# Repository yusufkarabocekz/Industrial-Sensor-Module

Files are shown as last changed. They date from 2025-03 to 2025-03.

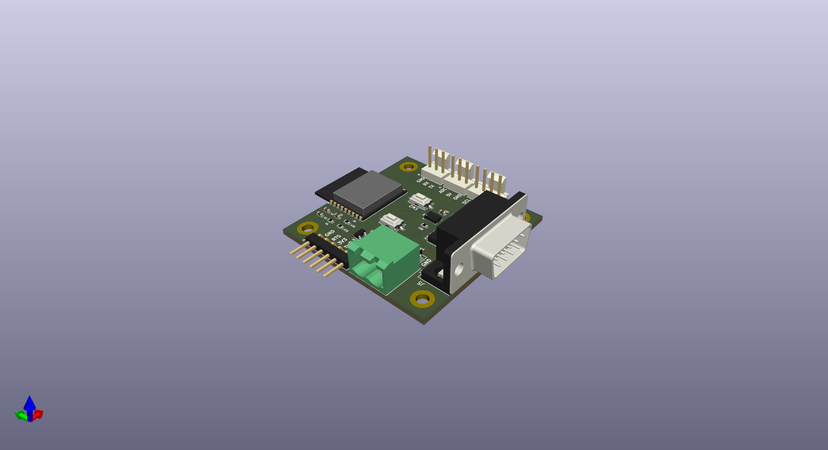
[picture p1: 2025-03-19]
Endüstriyel Sensör Modülü Front Cross.png

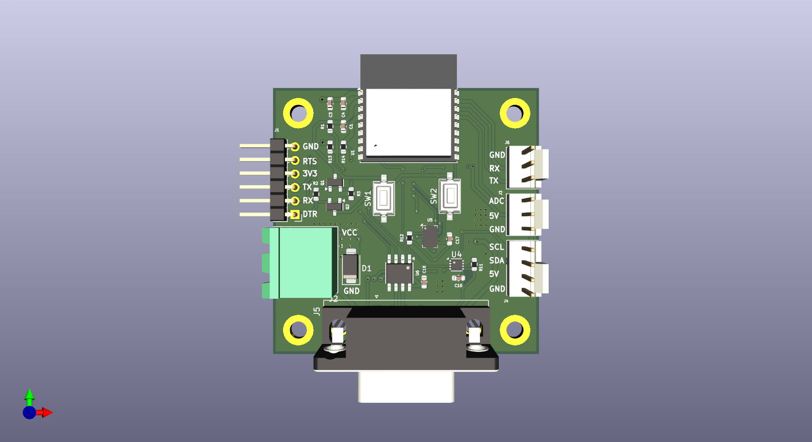
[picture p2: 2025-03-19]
Endüstriyel Sensör Modülü Front.png

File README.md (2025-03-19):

# Industrial Sensor Module

## Overview
This industrial sensor module is designed for factory automation applications, providing real-time environmental monitoring of temperature, humidity, and air quality (VOC). The module is built to withstand harsh industrial conditions and supports multiple communication protocols, making it a versatile solution for various automation systems.

## Features
- **Power Input:** 9-24V DC
- **Voltage Regulation:**
  - 5V and 3.3V regulators (LDO and DC-DC buck converter)
- **Sensors:**
  - SHT31 (Temperature & Humidity, I2C)
  - CCS811 (VOC and CO2, I2C)
  - External Analog Input (0-5V, read through 12-bit ADC)
- **Communication Interfaces:**
  - RS485 (Modbus RTU support)
  - UART & I2C external pins
  - ESP32C3 Mini onboard
- **PCB Specifications:**
  - **Dimensions:** 50mm x 50mm
  - **Layer Count:** 4-layer PCB for improved signal integrity and EMI resistance
  - **Terminal Blocks:** Phoenix Contact (or equivalent) screw terminals for RS485 and power input
  - **ESD Protection:** TVS diodes on input lines to ensure robustness

## PCB Design
The PCB layout is optimized to minimize the influence of airflow on sensor measurements. The module is compact, modular, and suitable for various industrial applications.

## PCB Images
### Front View
The front side of the PCB features the ESP32C3 Mini, sensor modules, and necessary components for power regulation and communication. 
Endüstriyel Sensör Modülü Front

### Back View
The back side of the PCB includes additional circuit traces, connectors, and protection components. 
Endüstriyel Sensör Modülü Front Bottom

### Angled View
This perspective provides a detailed look at the board's overall design, component placement, and the layout strategy used to optimize performance and durability.
Endüstriyel Sensör Modülü Front Cross

## Getting Started
### Hardware Setup
1. Provide a **9-24V DC** power input via the terminal block.
2. Connect RS485 for Modbus RTU communication or use UART/I2C for direct interfacing.
3. Read sensor values via ESP32C3 Mini or any other microcontroller with supported interfaces.

### Firmware Development
- The ESP32C3 Mini can be programmed using **ESP-IDF** or **Arduino framework**.
- Libraries required:
  - `Wire.h` for I2C communication
  - `ModbusMaster.h` for Modbus RTU communication (if needed)
  - `Adafruit_SHT31.h` for SHT31 sensor
  - `Adafruit_CCS811.h` for CCS811 sensor

## Gerber Files & Manufacturing
- The **Gerber files** are available in the `gerber/` directory.
- Recommended PCB manufacturing specs:
  - **Layer Count:** 4
  - **Copper Thickness:** 1oz
  - **Surface Finish:** ENIG

## Contact
For any inquiries or contributions, feel free to open an issue or reach out.

---
_Designed with KiCad._ Designed by Yusuf Karabocek

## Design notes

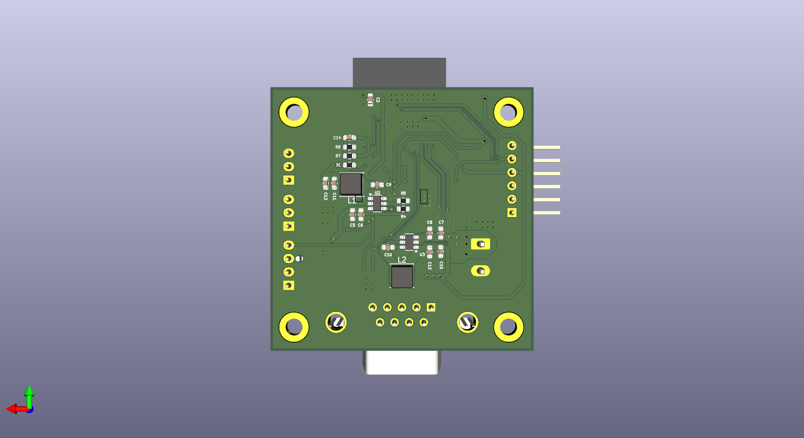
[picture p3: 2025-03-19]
Endüstriyel Sensör Modülü Front Bottom.png

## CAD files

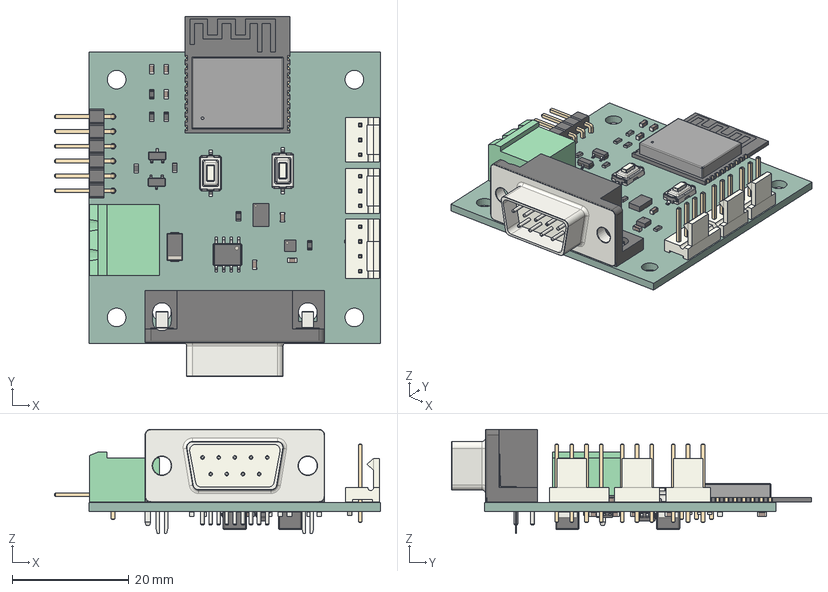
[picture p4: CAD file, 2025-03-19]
Endüstriyel Sensör Modülü.step
55.9 x 61.7 x 17.9 mm
C_0603_1608Metric x 18
D_SMA
SOIC-8_3.9x4.9mm_P1.27mm
SOT-23 x 2
SW_Tactile_SPST_NO_Straight_CK_PTS636Sx25SMTRLFS x 2
R_0603_1608Metric x 12
ESP32-C3-WROOM-02
PinHeader_1x06_P2.54mm_Horizontal
DSUB-9_Pins_Horizontal_P2.77x2.84mm_EdgePinOffset4.94mm_Housed_ MountingHolesOffset4.94mm
DFN-8-1EP_2x2mm_P0.5mm_EP0.6x1.2mm
PhoenixContact_MSTBA_2,5_2-G-5,08_1x02_P5.08mm_Horizontal
FanPinHeader_1x03_P2.54mm_Vertical x 2
FanPinHeader_1x04_P2.54mm_Vertical
AMS_LGA-10-1EP_2.7x4mm_P0.6mm
L_APV_ANR4030 x 2
TSOT-23-6
SOT-23-6
EndÃ¼striyel SensÃ¶r ModÃ¼lÃ¼_PCB

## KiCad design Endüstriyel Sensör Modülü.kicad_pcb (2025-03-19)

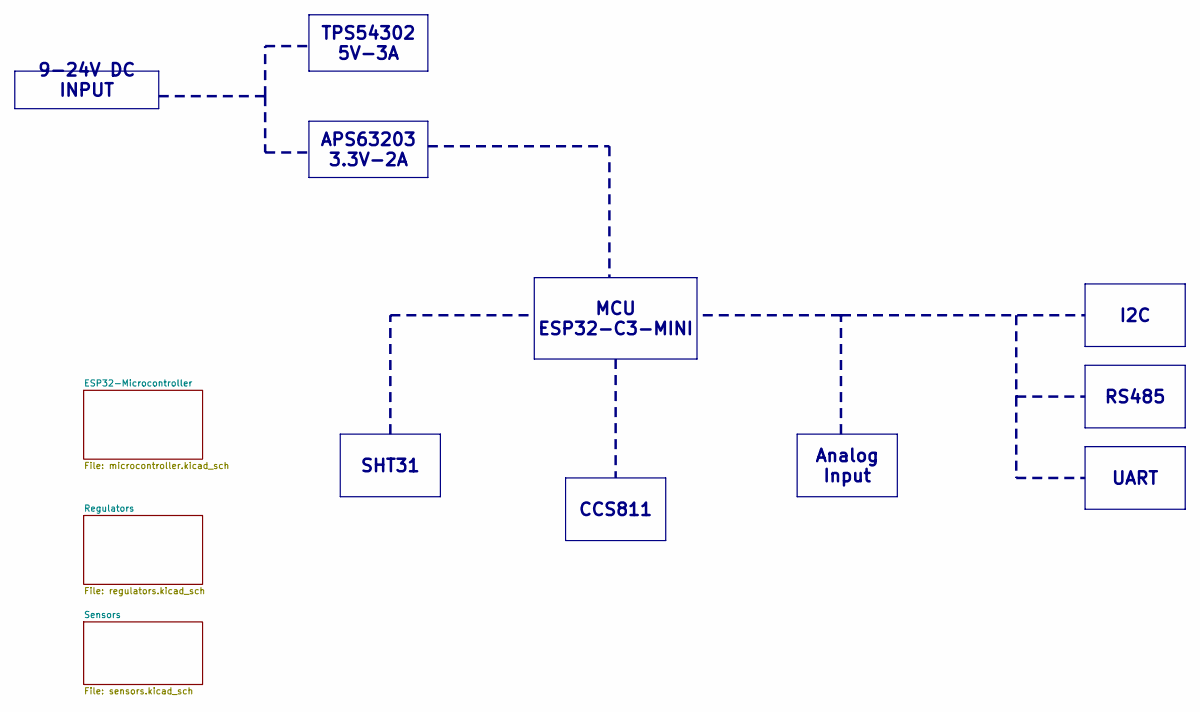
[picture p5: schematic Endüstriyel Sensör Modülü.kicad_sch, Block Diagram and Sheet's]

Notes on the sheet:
SHT31
MCU ESP32-C3-MINI
CCS811
APS63203 3.3V-2A
I2C
Analog Input
UART
9-24V DC INPUT
TPS54302 5V-3A
RS485

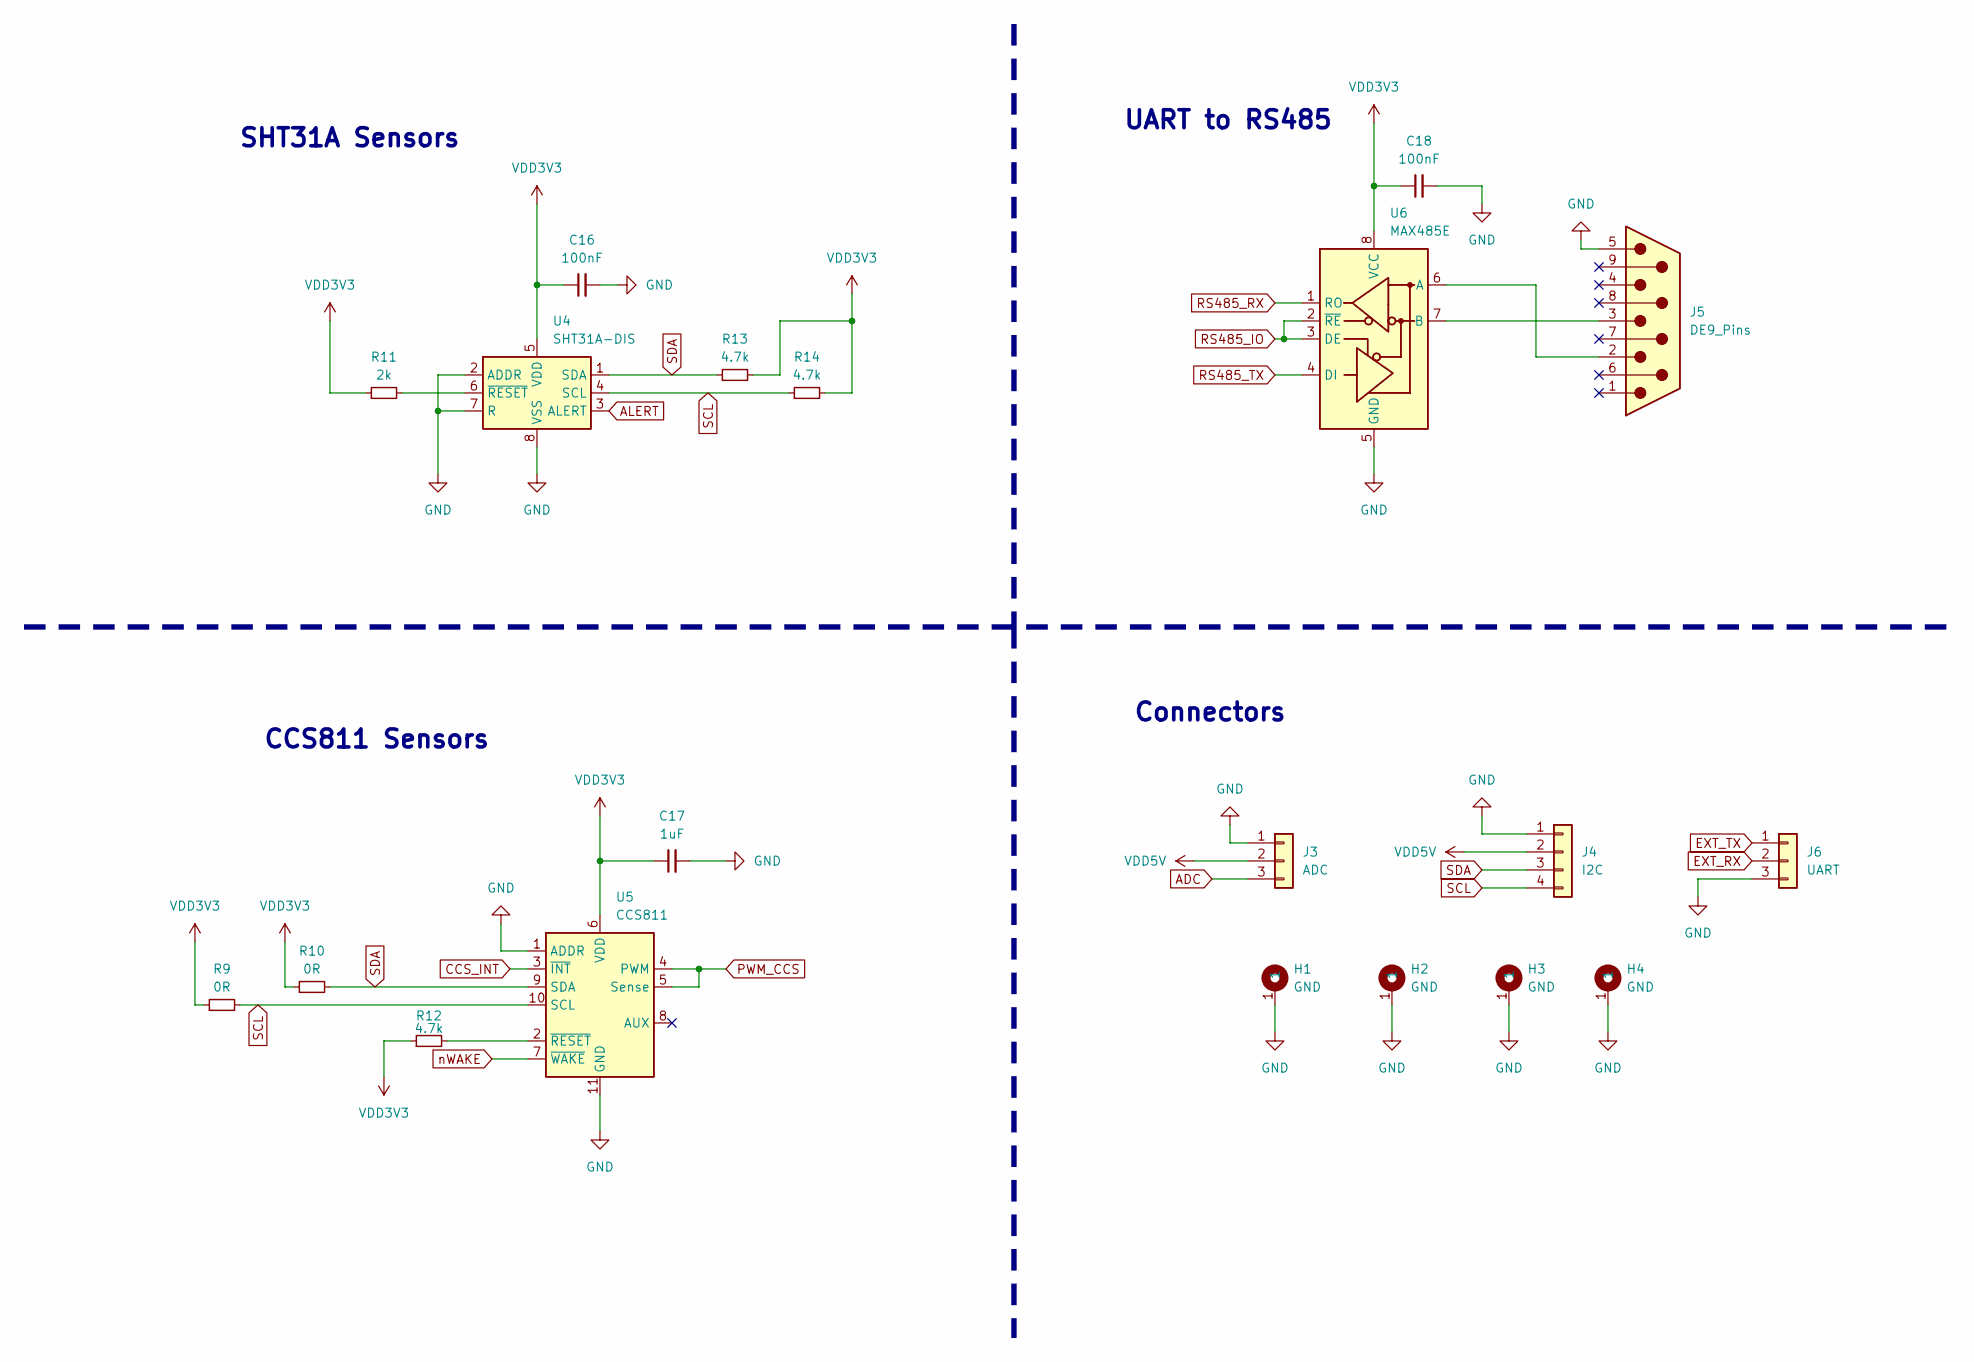
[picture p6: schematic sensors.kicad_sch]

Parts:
C16, C18: 100nF; C_0603_1608Metric
C17: 1uF; C_0603_1608Metric
H1, H2, H3, H4: GND; MountingHole_3.2mm_M3_ISO7380_Pad_TopBottom
J3: ADC; FanPinHeader_1x03_P2.54mm_Vertical
J4: I2C; FanPinHeader_1x04_P2.54mm_Vertical
J5: DE9_Pins; DSUB-9_Pins_Horizontal_P2.77x2.84mm_EdgePinOffset4.94mm_Hou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
J6: UART; FanPinHeader_1x03_P2.54mm_Vertical
R9, R10: 0R; R_0603_1608Metric
R11: 2k; R_0603_1608Metric
R12, R13, R14: 4.7k; R_0603_1608Metric
U4: SHT31A-DIS; DFN-8-1EP_2x2mm_P0.5mm_EP0.6x1.2mm
U5: CCS811; AMS_LGA-10-1EP_2.7x4mm_P0.6mm
U6: MAX485E; SOIC-8_3.9x4.9mm_P1.27mm

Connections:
ADC: J3.3; also elsewhere on the board
ALERT: U4.3 (ALERT); also elsewhere on the board
CCS_INT: U5.3 (~INT); also elsewhere on the board
EXT_RX: J6.2; also elsewhere on the board
EXT_TX: J6.1; also elsewhere on the board
GND: C16.2, C17.2, C18.2, H1.1, H2.1, H3.1, H4.1, J3.1, J4.1, J5.5, J6.3, U4.2 (ADDR), U4.7 (R), U4.8 (VSS), U4.9 (VSS), U5.1 (ADDR), U5.11 (GND), U6.5 (GND); also elsewhere on the board
unnamed: R11.2, U4.6 (~RESET)
unnamed: R12.2, U5.2 (~RESET)
unnamed: J5.2, U6.6 (A)
unnamed: J5.3, U6.7 (B)
PWM_CCS: U5.4 (PWM), U5.5 (Sense); also elsewhere on the board
RS485_IO: U6.2 (~RE), U6.3 (DE); also elsewhere on the board
RS485_RX: U6.1 (RO); also elsewhere on the board
RS485_TX: U6.4 (DI); also elsewhere on the board
SCL: J4.4, R9.2, R14.1, U4.4 (SCL), U5.10 (SCL); also elsewhere on the board
SDA: J4.3, R10.2, R13.1, U4.1 (SDA), U5.9 (SDA); also elsewhere on the board
VDD3V3: C16.1, C17.1, C18.1, R9.1, R10.1, R11.1, R12.1, R13.2, R14.2, U4.5 (VDD), U5.6 (VDD), U6.8 (VCC); also elsewhere on the board
VDD5V: J3.2, J4.2; also elsewhere on the board
nWAKE: U5.7 (~WAKE); also elsewhere on the board

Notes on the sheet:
UART to RS485
CCS811 Sensors
Connectors
SHT31A Sensors

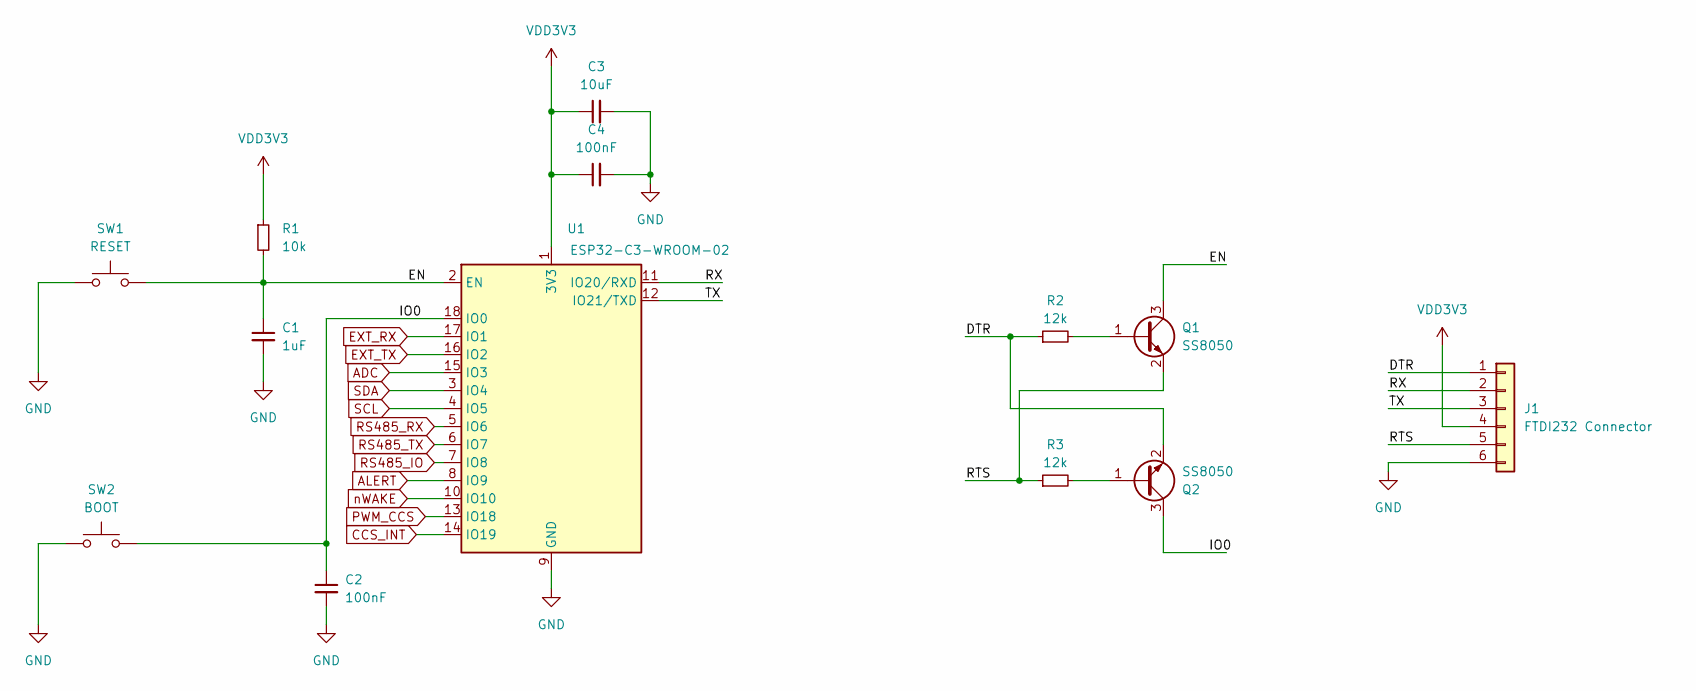
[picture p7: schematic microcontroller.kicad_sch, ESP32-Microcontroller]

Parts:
C1: 1uF; C_0603_1608Metric
C2, C4: 100nF; C_0603_1608Metric
C3: 10uF; C_0603_1608Metric
J1: FTDI232 Connector; PinHeader_1x06_P2.54mm_Horizontal
Q1, Q2: SS8050; SOT-23
R1: 10k; R_0603_1608Metric
R2, R3: 12k; R_0603_1608Metric
SW1: RESET; SW_Tactile_SPST_NO_Straight_CK_PTS636Sx25SMTRLFS
SW2: BOOT; SW_Tactile_SPST_NO_Straight_CK_PTS636Sx25SMTRLFS
U1: ESP32-C3-WROOM-02

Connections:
/ESP32-Microcontroller/DTR: J1.1, Q2.2 (E), R2.1
/ESP32-Microcontroller/EN: C1.1, Q1.3 (C), R1.2, SW1.2, U1.2 (EN)
/ESP32-Microcontroller/IO0: C2.1, Q2.3 (C), SW2.2, U1.18 (IO0)
/ESP32-Microcontroller/RTS: J1.5, Q1.2 (E), R3.1
/ESP32-Microcontroller/RX: J1.2, U1.11 (IO20/RXD)
/ESP32-Microcontroller/TX: J1.3, U1.12 (IO21/TXD)
ADC: U1.15 (IO3); also elsewhere on the board
ALERT: U1.8 (IO9); also elsewhere on the board
CCS_INT: U1.14 (IO19); also elsewhere on the board
EXT_RX: U1.17 (IO1); also elsewhere on the board
EXT_TX: U1.16 (IO2); also elsewhere on the board
GND: C1.2, C2.2, C3.2, C4.2, J1.6, SW1.1, SW2.1, U1.9 (GND), U1.19 (GND); also elsewhere on the board
unnamed: Q1.1 (B), R2.2
unnamed: Q2.1 (B), R3.2
PWM_CCS: U1.13 (IO18); also elsewhere on the board
RS485_IO: U1.7 (IO8); also elsewhere on the board
RS485_RX: U1.5 (IO6); also elsewhere on the board
RS485_TX: U1.6 (IO7); also elsewhere on the board
SCL: U1.4 (IO5); also elsewhere on the board
SDA: U1.3 (IO4); also elsewhere on the board
VDD3V3: C3.1, C4.1, J1.4, R1.1, U1.1 (3V3); also elsewhere on the board
nWAKE: U1.10 (IO10); also elsewhere on the board

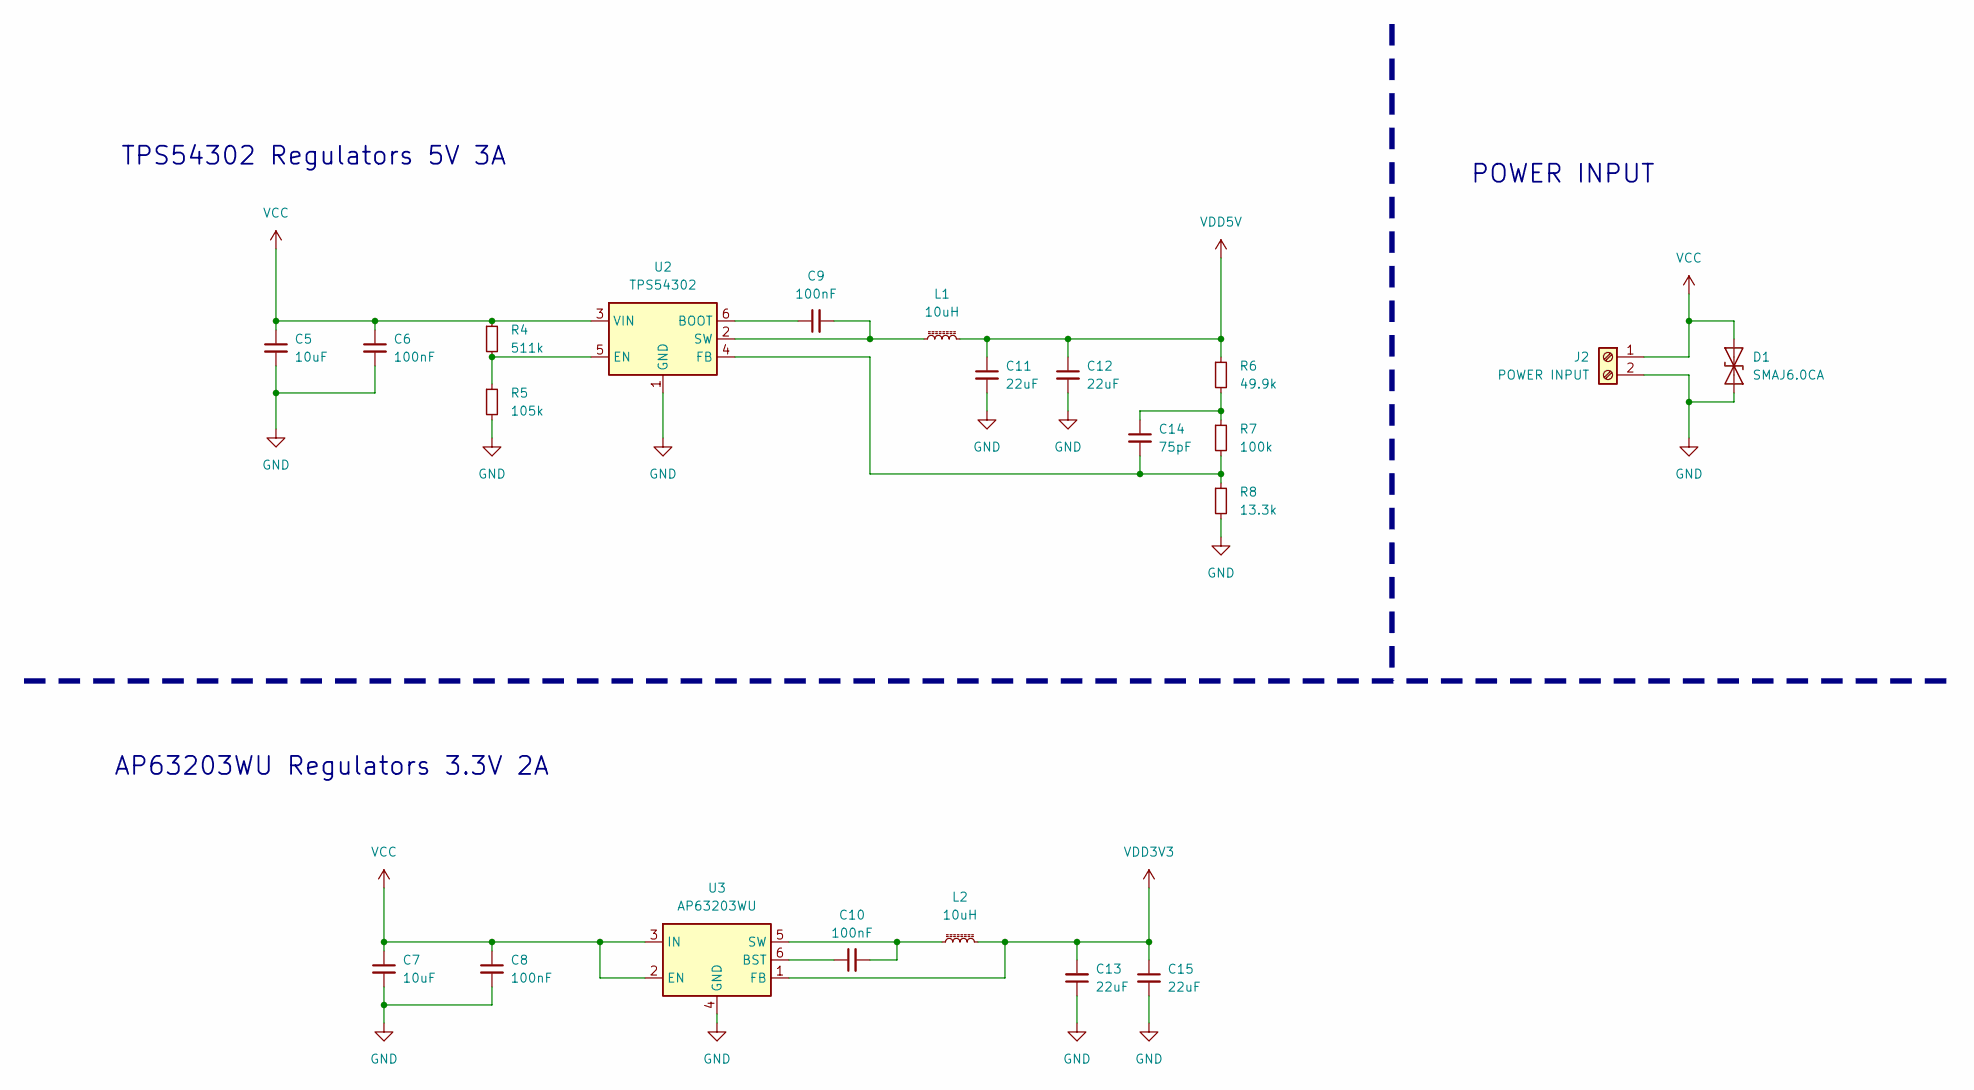
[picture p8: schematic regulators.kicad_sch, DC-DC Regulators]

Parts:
C5, C7: 10uF; C_0603_1608Metric
C6, C8, C9, C10: 100nF; C_0603_1608Metric
C11, C12, C13, C15: 22uF; C_0603_1608Metric
C14: 75pF; C_0603_1608Metric
D1: SMAJ6.0CA; D_SMA
J2: POWER INPUT; PhoenixContact_MSTBA_2,5_2-G-5,08_1x02_P5.08mm_Horizontal
L1, L2: 10uH; L_APV_ANR4030
R4: 511k; R_0603_1608Metric
R5: 105k; R_0603_1608Metric
R6: 49.9k; R_0603_1608Metric
R7: 100k; R_0603_1608Metric
R8: 13.3k; R_0603_1608Metric
U2: TPS54302; SOT-23-6
U3: AP63203WU; TSOT-23-6

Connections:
GND: C5.2, C6.2, C7.2, C8.2, C11.2, C12.2, C13.1, C15.2, D1.1 (A1), J2.2, R5.2, R8.2, U2.1 (GND), U3.4 (GND); also elsewhere on the board
unnamed: C14.1, R6.2, R7.1
unnamed: C9.1, U2.6 (BOOT)
unnamed: R4.2, R5.1, U2.5 (EN)
unnamed: C14.2, R7.2, R8.1, U2.4 (FB)
unnamed: C9.2, L1.1, U2.2 (SW)
unnamed: C10.1, U3.6 (BST)
unnamed: C10.2, L2.1, U3.5 (SW)
VCC: C5.1, C6.1, C7.1, C8.1, D1.2 (A2), J2.1, R4.1, U2.3 (VIN), U3.2 (EN), U3.3 (IN)
VDD3V3: C13.2, C15.1, L2.2, U3.1 (FB); also elsewhere on the board
VDD5V: C11.1, C12.1, L1.2, R6.1; also elsewhere on the board

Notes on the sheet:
TPS54302 Regulators 5V 3A
POWER INPUT
AP63203WU Regulators 3.3V 2A

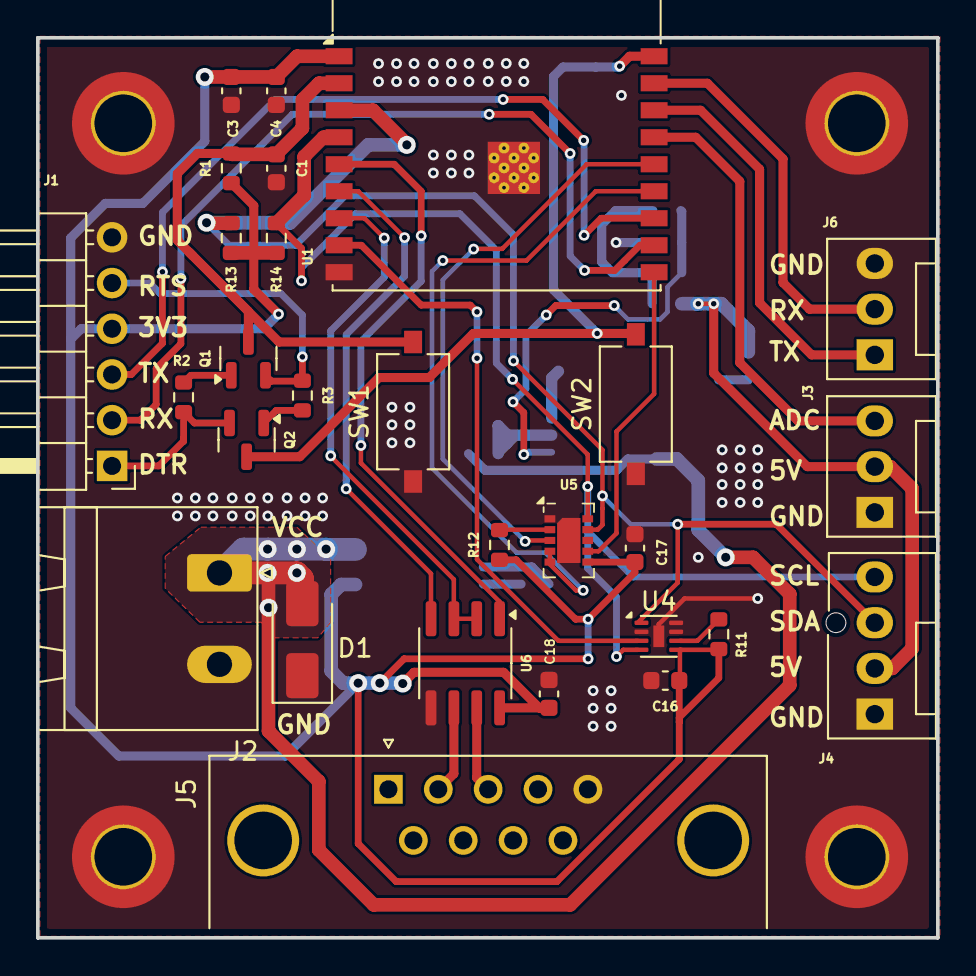
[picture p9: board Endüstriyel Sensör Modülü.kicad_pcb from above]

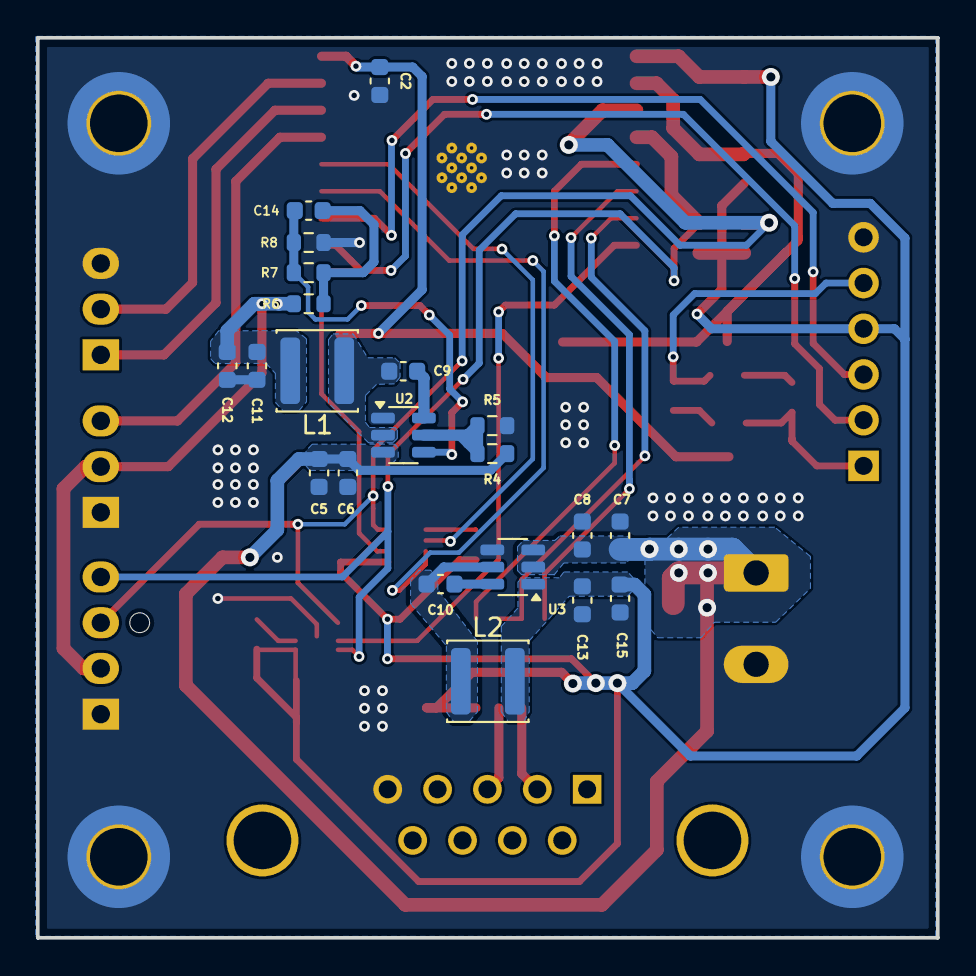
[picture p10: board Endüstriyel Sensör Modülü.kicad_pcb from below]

Board: 4 copper layers, 50.0 x 50.0 mm, 53 parts (21 on the bottom side), 35 nets.
